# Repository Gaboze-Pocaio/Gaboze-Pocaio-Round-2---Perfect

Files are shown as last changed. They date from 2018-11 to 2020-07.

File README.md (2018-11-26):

-----

# Where Can I Buy One
> You can purchase an assembled Gaboze Pocaio - Round 2 on [Tindie](https://www.tindie.com/products/thirtytwoteeth/gaboze-pocaio-round-2/)

[](https://www.tindie.com/products/thirtytwoteeth/gaboze-pocaio-round-2/)

-----

# Gaboze Pocaio
> This is it!

Based on the popularity of the original [Gaboze Pocaio](https://github.com/32teeth/GabozePocaio-Round1) and it's many updates. We have taken the *Gaboze Pocaio - Plus Edition* which featured the 2.6" TFT *(ILI9342)* and added a few more features

Project Code Name: ***'Play It Again'***

## Introduction
> Do we need one?

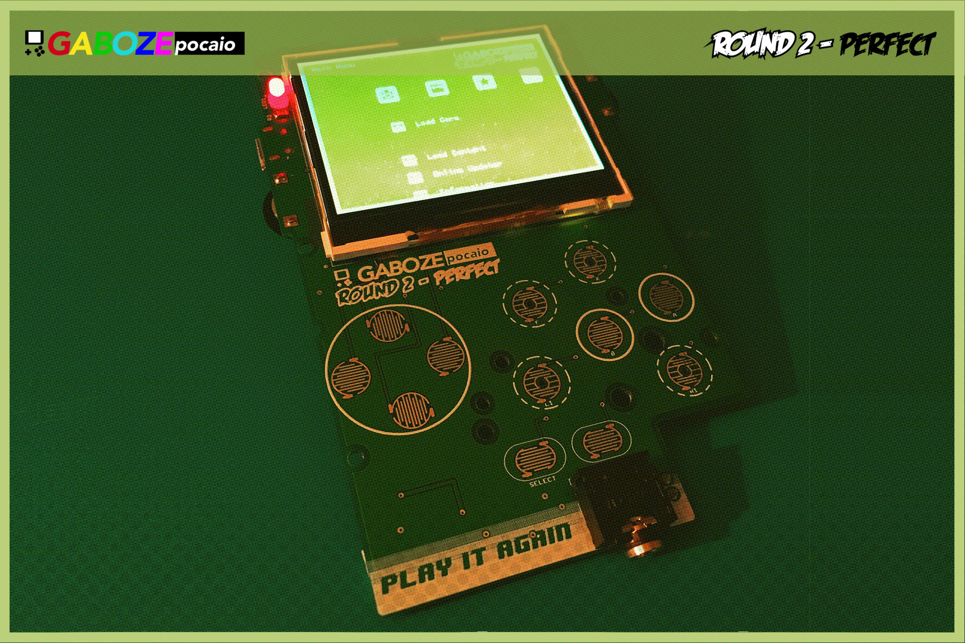
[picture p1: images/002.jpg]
Play It Again


### Features
> Things you can find on this kit

- 2.6" TFT LCD
- USB peripheral support for *3.3v accessories* (ie: keyboards)
- Brightness Control Thumbwheel
- Volume Control Thumbwheel
- Power LED - 3mm diffused
- New Conductive Pads
- Through Hole Raspberry Pi Zero Mounting Header
- Battery Charger (TP4056 Module)
- Headphone Jack (LM4857)
- Speaker capability (LM4857)
- Audio Amp (LM4857)

| Top Side Features | Bottom Side Features |
| - | - |
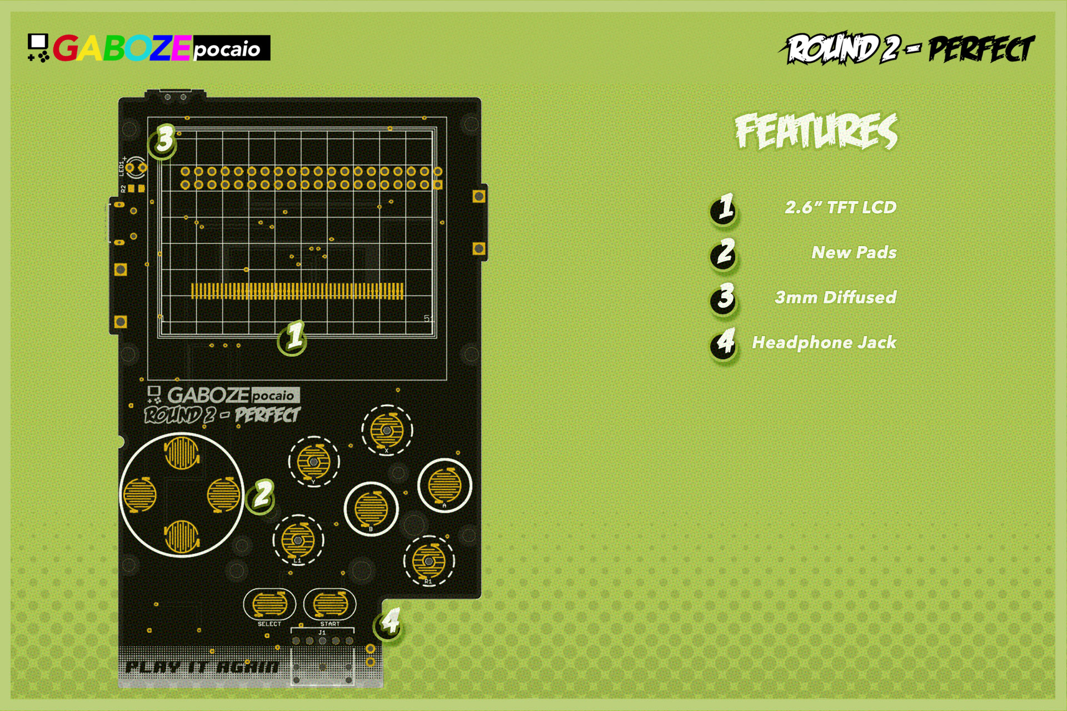
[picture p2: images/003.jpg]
Top
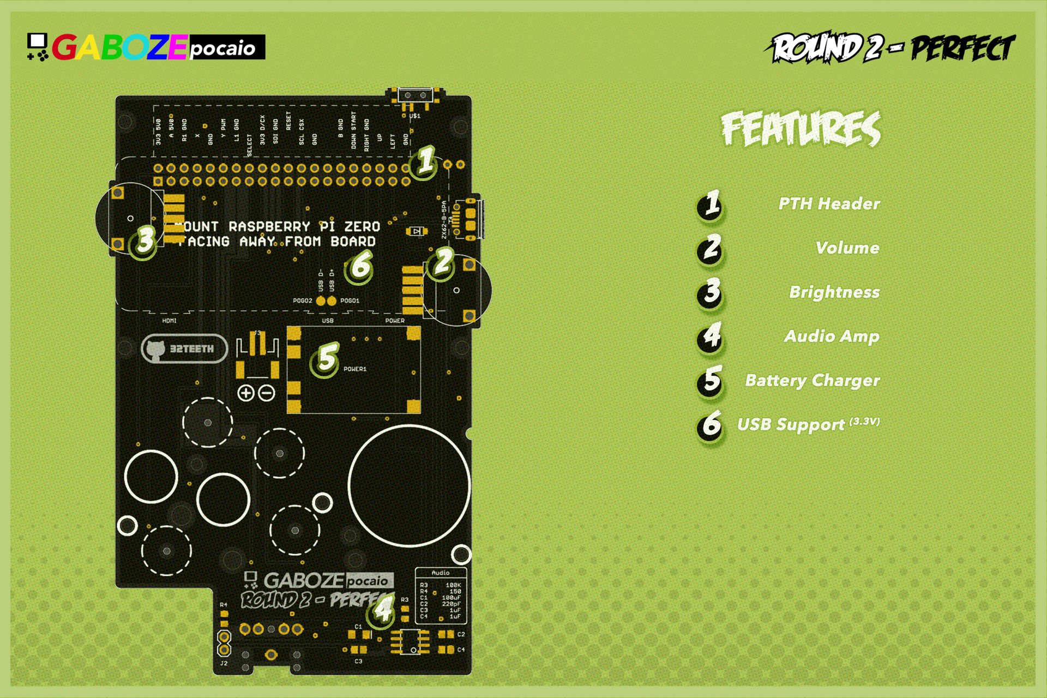
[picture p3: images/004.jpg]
Bottom
|  |  |

### Platform Support:

- [x] [Emulation Station](http://www.emulationstation.org/)
- [x] [Lakka](http://www.lakka.tv/)
- [x] [RetroPie](https://retropie.org.uk/)

*For [Lakka](http://www.lakka.tv/) implementation you can follow the ['paint by numbers' tutorial](https://github.com/32teeth/Lakka-For-Gaboze-Pocaio)*

#### New Feature Discussion
> A little more behind the features

##### TFT
> A new screen

An adoption from the *Gaboze Pocaio - Plus Edition*. The screen is now a 2.6" TFT, which fills the screen area of the Game Boy Pocket shell much better. No more resizing of the video driver output!

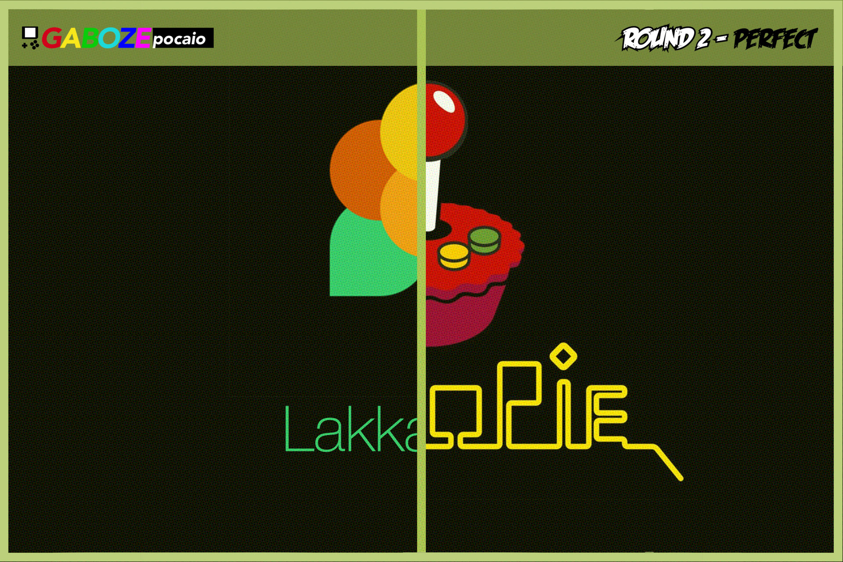
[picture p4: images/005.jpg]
Lakka or RetroPie


##### Brightness Control
> Mechanical Adjustment FTW

Although there are many implementations of *software* based screen brightness adjustment. This model features a **thubwheel**, which means you don't need to worry about knowing how, or where to put the *software* based controls.

This also allows for using different *Operating Systems* and having brightness control out of the box

##### Through Hole Header
> No more loose connections

With the new Raspberry Pi Zero mounting system using a through hole header, you will no longer loosen the pin connection if using an unregulated (non temperature) control soldering iron...   ...yay

The short insulation on the header also means you can mount the Raspberry Pi flat against the headers

##### New Conductive Pads
> Better response. Simply put

With a redesigned conductive pad, you can now have a better response rate to your silicon aftermarket pads.

##### USB peripheral support
> No connection? No Problem

This is a 3.3V USB peripheral support, like keyboards (not the LED mechanical ones), older joysticks / gamepads *(can you say retro pads!)*

One of the most requested features is to be able to use your keyboard and terminal without having to connect to the network, SSH, SCP, or FTP.

##### Power LED
> Domed and diffused

We replaced the surface mount power indicator LED with a through hole domed and diffused 3mm LED. This fits perfectly in the LED hole of the original and aftermarket *Game Boy Pocket* shell

## What you need
> Batteries not included

In order to complete your build. You will need:

- Raspberry Pi Zero W
- LiPo Battery
- Micro SD Card
- Gameboy Pocket Shell

## Releases
> Retro Pie or Lakka - You Decide

* [Retro Pie](https://github.com/32teeth/GabozePocaio-Round2/releases/tag/RetroPie)
* [Lakka](https://github.com/32teeth/GabozePocaio-Round2/releases/tag/Lakka)

### Direct Downloads

#### Retro Pie
* [IMG](http://gameboy.32teeth.org/Gaboze-Round2-RetroPie.img)
* [GZIP](http://gameboy.32teeth.org/Gaboze-Round2-RetroPie.gz)

#### Lakka
* [IMG](http://gameboy.32teeth.org/Gaboze-Round2-Lakka.img)
* [GZIP](http://gameboy.32teeth.org/Gaboze-Round2-Lakka.gz)

### Get In Touch

|    [](https://github.com/32teeth)[](https://www.instagram.com/gabozepocaio/)[](https://www.facebook.com/messages/t/gabozepocaio)[](https://www.paypal.me/32teeth/5USD)  |
| ---- |
| Find us on the internet and lets chat |

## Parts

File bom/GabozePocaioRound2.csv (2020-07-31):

Designator | Description | Manufacturer Part Number | Purchase Link | Quantity
D1 | DIODE SCHOTTKY 20V 1A SOD123FL | SM5817PL-TP | https://www.digikey.ca/product-detail/en/micro-commercial-co/SM5817PL-TP/SM5817PL-TPMSCT-ND/1793410 | 1
R2 | RES SMD 1.5K OHM 0.1% 1/4W 0805 | ERJ-PB6B1501V | https://www.digikey.ca/product-detail/en/panasonic-electronic-components/ERJ-PB6B1501V/P20612CT-ND/6214867 | 1
R3 | RES 100K OHM 5% 1/4W 0805 | RPC0805JT100KCT | https://www.digikey.ca/product-detail/en/stackpole-electronics-inc/RPC0805JT100K/RPC0805JT100KCT-ND/5766007 | 1
R4 | RES 150 OHM 1% 1/4W 0805 | RNCP0805FTD150R | https://www.digikey.ca/product-detail/en/stackpole-electronics-inc/RNCP0805FTD150R/RNCP0805FTD150RCT-ND/2240550 | 1
R5, R10 | Replacement Volume Switch for Game boy | N/A | https://www.aliexpress.com/item/Replacement-Volume-Switch-for-Game-boy-for-GBA-GBC-Motherboard-Potentiomete-100pcs-lot/32830491244.html | 2
C1 | CAP TANT 100UF 4V 20% 1206 | F930G107MAA | https://www.digikey.ca/product-detail/en/avx-corporation/F930G107MAA/478-8134-1-ND/4005954 | 1
C3,C4 | CAP CER 1UF 25V X7R 0805 | C0805C105K3RACTU | https://www.digikey.ca/product-detail/en/kemet/C0805C105K3RACTU/399-8004-1-ND/3471727 | 2
C2 | CAP CER 0.22UF 50V X7R 0805 | C0805C224K5RACTU | https://www.digikey.ca/product-detail/en/kemet/C0805C224K5RACTU/399-3491-1-ND/754784 | 1
J1 | CONN JACK STEREO 3.5MM R/A | CP1-3525NG-PI-ND | https://www.digikey.ca/product-detail/en/cui-inc/SJ1-3525NG-PI/CP1-3525NG-PI-ND/2295991 | 1
J2 | SPEAKER 8OHM 250MW TOP PORT 80DB | PSR-20F08S-JQ | https://www.digikey.ca/product-detail/en/mallory-sonalert-products-inc/PSR-20F08S-JQ/458-1122-ND/2071438 | 1
J3 | CONN HEADER PH SIDE 2POS 2MM SMD | S2B-PH-SM4-TB(LF)(SN | https://www.digikey.ca/product-detail/en/jst-sales-america-inc/S2B-PH-SM4-TB(LF)(SN)/455-1749-1-ND/926846 | 1
J4 | CONN RCPT USB MICRO B SMD | ZX62D-B-5P8(30) | https://www.digikey.ca/product-detail/en/hirose-electric-co-ltd/ZX62D-B-5P8-30/H125272CT-ND/5994758 | 1
U1 | IC AMP AUDIO PWR 1W MONO 8SOIC | LM4875MX-NOPB | https://www.digikey.ca/product-detail/en/texas-instruments/LM4875MX-NOPB/296-35282-1-ND/3738990 | 1
LED1 | LED RED DIFFUSED 3MM ROUND T/H | 151031SS04000 | https://www.digikey.ca/product-detail/en/wurth-electronics-inc/151031SS04000/732-5005-ND/4489979 | 1
U$1 | SWITCH SLIDE SPDT 300MA 4V | MA12RTR | https://www.digikey.ca/product-detail/en/apem-inc/MA12RTR/679-1847-1-ND/1973774 | 1
U$2 | 2.6 inch TFT liquid horizontal screen ILI9342 3/4 line SPI MCU8 bit 16 touch | N/A | https://www.aliexpress.com/item/-/32861496981.html | 1
PI1 | CONN HEADER .100" 40POS SNGL TIN | TLW-120-06-T-D | https://www.digikey.ca/product-detail/en/samtec-inc/TLW-120-06-T-D/SAM1097-20-ND/1104960 | 1
POWER1 | Lithium Battery Charging Board | N/A | https://www.aliexpress.com/item/Free-Shipping-1PCS-5V-Micro-USB-1A-18650-Lithium-Battery-Charging-Board-With-Protection-Charger-Module/32476957358.html | 1
POGO1, POGO2 | ULTRA LOW PROFILE SPRING PIN | 0965-0-15-20-80-14-11-0 | https://www.digikey.ca/product-detail/en/0965-0-15-20-80-14-11-0/ED1649-ND/2784013 | 2

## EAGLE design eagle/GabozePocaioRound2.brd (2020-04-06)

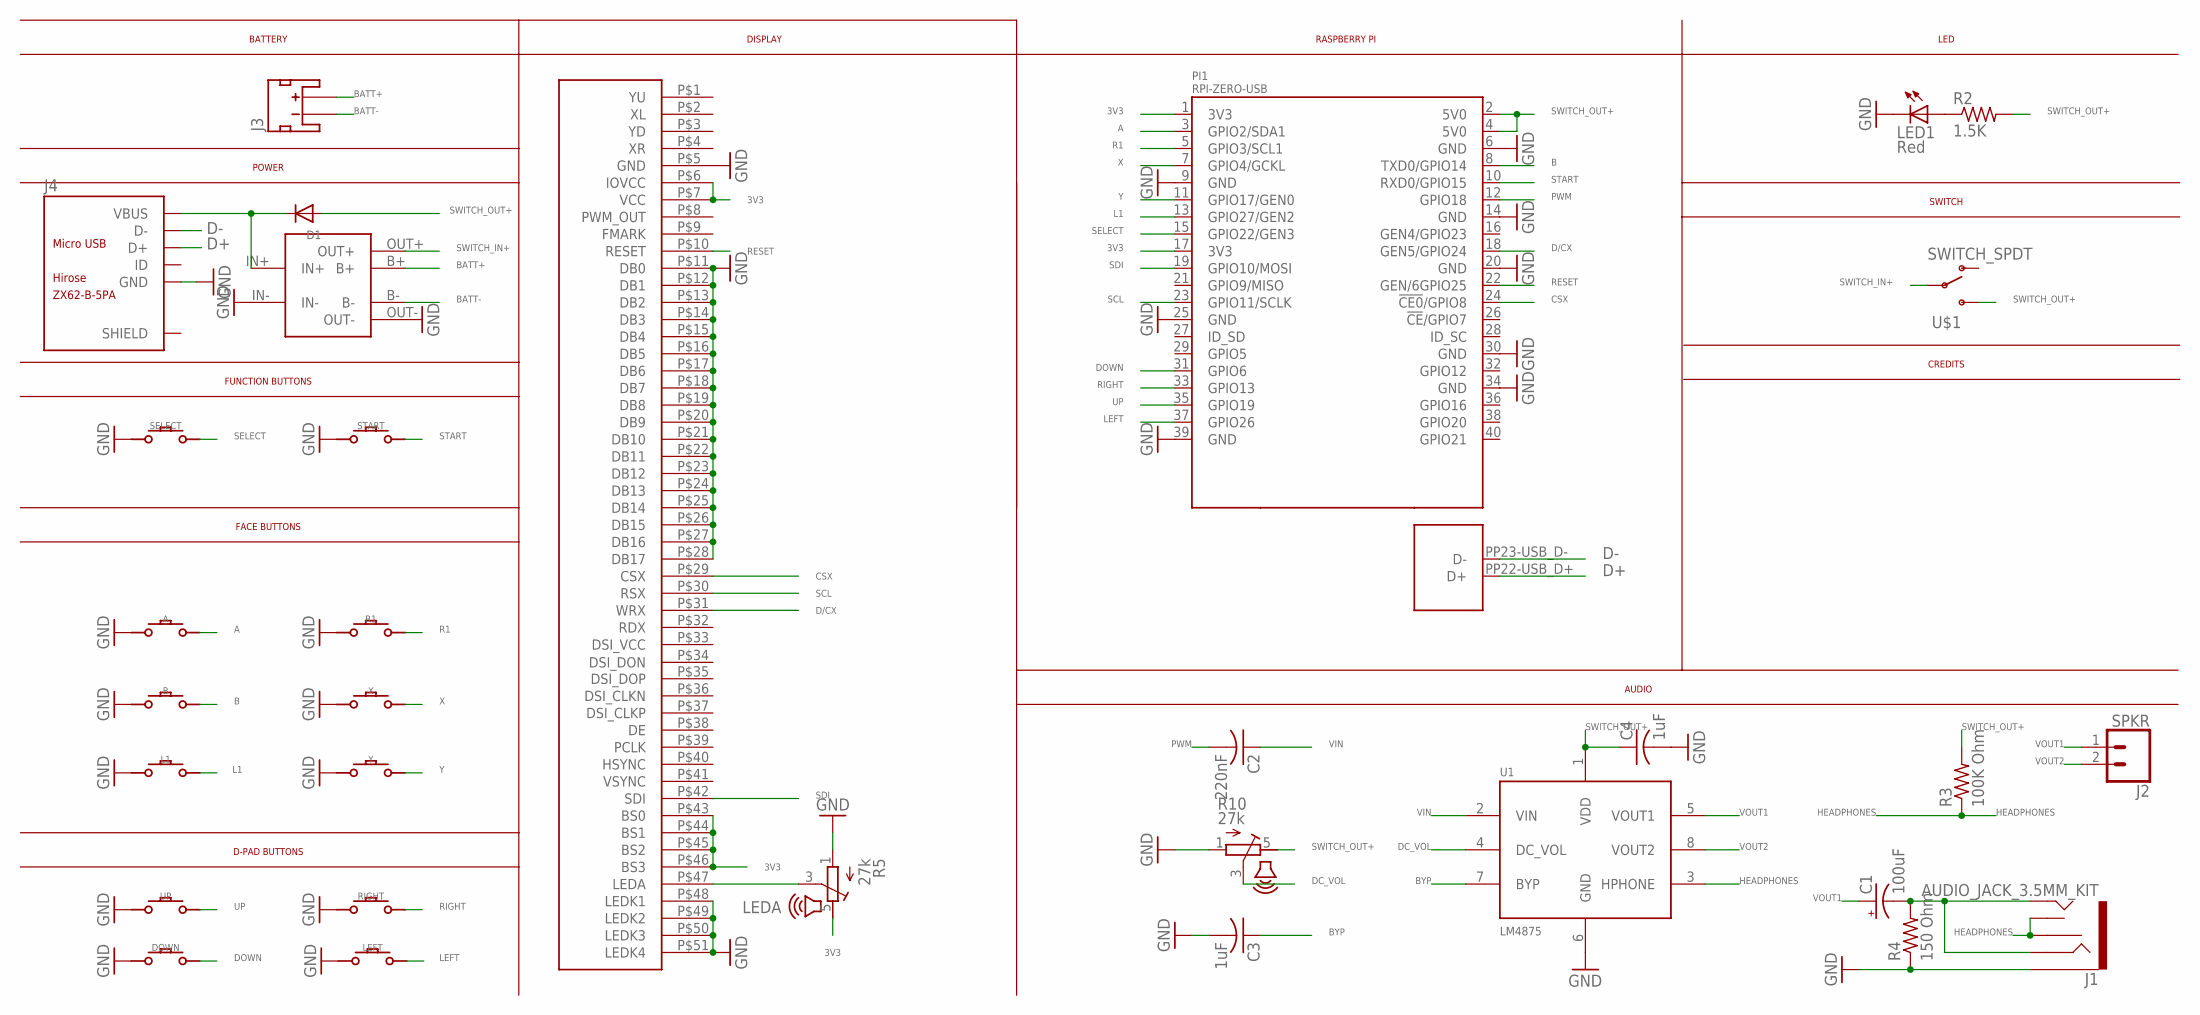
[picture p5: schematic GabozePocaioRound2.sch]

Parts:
A: CONDUCTIVE_BUTTONCONDUCTIVE_BUTTON_THICK; CONDUCTIVE_BUTTON_THICK
B: CONDUCTIVE_BUTTONCONDUCTIVE_BUTTON_THICK; CONDUCTIVE_BUTTON_THICK
C1: 100uF; EIA3216
C2: 220nF; C0805
C3, C4: 1uF; C0805
D1: DIODE_SOD-123FL; SOD-123FL
DOWN: CONDUCTIVE_BUTTONCONDUCTIVE_BUTTON_DIRECTIONAL_TH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; CONDUCTIVE_BUTTON_DIRECTIONAL_THICK
J1: AUDIO_JACK_3.5MM_KIT; AUDIO-JACK-KIT
J2: SPKR; 1X02
J3: Batt Conn; JST-2-SMD
J4: ZX62-B-5PA; MICRO-USB5+6P-SMD-0.65-AB
L1: CONDUCTIVE_BUTTON_DRILLCONDUCTIVE_BUTTON_DRILL_TH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; CONDUCTIVE_BUTTON_THICK_DRILL
LED1: Red; LED3MM
LEFT: CONDUCTIVE_BUTTONCONDUCTIVE_BUTTON_DIRECTIONAL_TH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; CONDUCTIVE_BUTTON_DIRECTIONAL_THICK
PI1: RPI-ZERO-USB; RPI-ZERO-TH-USB-POGO
POWER1: TP4056
R1: CONDUCTIVE_BUTTON_DRILLCONDUCTIVE_BUTTON_DRILL_TH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; CONDUCTIVE_BUTTON_THICK_DRILL
R2: 1.5K; R0805
R3: 100K Ohm; R0805
R4: 150 Ohm; R0805
R5, R10: 27k; VOLUME
RIGHT: CONDUCTIVE_BUTTONCONDUCTIVE_BUTTON_DIRECTIONAL_TH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; CONDUCTIVE_BUTTON_DIRECTIONAL_THICK
SELECT: CONDUCTIVE_BUTTON_STARTSELECTCONDUCTIVE_BUTTON_TH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; CONDUCTIVE_BUTTON_THICK_STARTSELECT
START: CONDUCTIVE_BUTTON_STARTSELECTCONDUCTIVE_BUTTON_TH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; CONDUCTIVE_BUTTON_THICK_STARTSELECT
U1: LM4875; SOIC8
U$1: SWITCH_SPDT; KPS-1290
U$2: TFT-DISPLAY-2.6-51PIN
UP: CONDUCTIVE_BUTTONCONDUCTIVE_BUTTON_DIRECTIONAL_TH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; CONDUCTIVE_BUTTON_DIRECTIONAL_THICK
X: CONDUCTIVE_BUTTON_DRILLCONDUCTIVE_BUTTON_DRILL_TH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; CONDUCTIVE_BUTTON_THICK_DRILL
Y: CONDUCTIVE_BUTTON_DRILLCONDUCTIVE_BUTTON_DRILL_TH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; CONDUCTIVE_BUTTON_THICK_DRILL

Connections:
3V3: PI1.1 (3V3), PI1.17 (3V3), R5.5 (E), U$2.P$6 (IOVCC), U$2.P$7 (VCC), U$2.P$43 (BS0), U$2.P$44 (BS1), U$2.P$45 (BS2), U$2.P$46 (BS3)
A: A.P$ACTIVE, PI1.3 (GPIO2/SDA1)
B: B.P$ACTIVE, PI1.8 (TXD0/GPIO14)
BATT+: J3.2 (+), POWER1.B+
BATT-: J3.1 (-), POWER1.B-
BYP: C3.1, U1.7 (BYP)
CSX: PI1.24 (!CE0!/GPIO8), U$2.P$29 (CSX)
D+: J4.3 (D+), PI1.PP22-USB_D+ (D+)
D-: J4.2 (D-), PI1.PP23-USB_D- (D-)
D/CX: PI1.18 (GEN5/GPIO24), U$2.P$31 (WRX)
DC_VOL: R10.3 (S), U1.4 (DC_VOL)
DOWN: DOWN.P$ACTIVE, PI1.31 (GPIO6)
GND: A.P$GND, B.P$GND, C3.2, C4.2, DOWN.P$GND, J1.SLEEVE, J4.5 (GND), L1.P$GND, LED1.K (C), LEFT.P$GND, PI1.6 (GND), PI1.9 (GND), PI1.14 (GND), PI1.20 (GND), PI1.25 (GND), PI1.30 (GND), PI1.34 (GND), PI1.39 (GND), POWER1.IN-, POWER1.OUT-, R1.P$GND, R4.1, R5.1 (A), R10.1 (A), RIGHT.P$GND, SELECT.P$GND, SELECT.P$GND1 (P$GND), SELECT.P$GND2 (P$GND), SELECT.P$GND3 (P$GND), START.P$GND, START.P$GND1 (P$GND), START.P$GND2 (P$GND), START.P$GND3 (P$GND), U1.6 (GND), U$2.P$5 (GND), U$2.P$11 (DB0), U$2.P$12 (DB1), U$2.P$13 (DB2), U$2.P$14 (DB3), U$2.P$15 (DB4), U$2.P$16 (DB5), U$2.P$17 (DB6), U$2.P$18 (DB7), U$2.P$19 (DB8), U$2.P$20 (DB9), U$2.P$21 (DB10), U$2.P$22 (DB11), U$2.P$23 (DB12), U$2.P$24 (DB13), U$2.P$25 (DB14), U$2.P$26 (DB15), U$2.P$27 (DB16), U$2.P$28 (DB17), U$2.P$48 (LEDK1), U$2.P$49 (LEDK2), U$2.P$50 (LEDK3), U$2.P$51 (LEDK4), UP.P$GND, X.P$GND, Y.P$GND
HEADPHONES: J1.RSH, J1.TSH, R3.1, U1.3 (HPHONE)
L1: L1.P$ACTIVE, PI1.13 (GPIO27/GEN2)
LED: LED1.A, R2.1
LEDA: R5.3 (S), U$2.P$47 (LEDA)
LEFT: LEFT.P$ACTIVE, PI1.37 (GPIO26)
PWM: C2.2, PI1.12 (GPIO18)
R1: PI1.5 (GPIO3/SCL1), R1.P$ACTIVE
RESET: PI1.22 (GEN/6GPIO25), U$2.P$10 (RESET)
RIGHT: PI1.33 (GPIO13), RIGHT.P$ACTIVE
SCL: PI1.23 (GPIO11/SCLK), U$2.P$30 (RSX)
SDI: PI1.19 (GPIO10/MOSI), U$2.P$42 (SDI)
SELECT: PI1.15 (GPIO22/GEN3), SELECT.P$ACTIVE, SELECT.P$ACTIVE1 (P$ACTIVE), SELECT.P$ACTIVE2 (P$ACTIVE), SELECT.P$ACTIVE3 (P$ACTIVE)
START: PI1.10 (RXD0/GPIO15), START.P$ACTIVE, START.P$ACTIVE1 (P$ACTIVE), START.P$ACTIVE2 (P$ACTIVE), START.P$ACTIVE3 (P$ACTIVE)
SWITCH_IN+: POWER1.OUT+, U$1.P
SWITCH_OUT+: C4.1, D1.A, PI1.2 (5V0), PI1.4 (5V0), R2.2, R3.2, R10.5 (E), U1.1 (VDD), U$1.S
UP: PI1.35 (GPIO19), UP.P$ACTIVE
VIN: C2.1, U1.2 (VIN)
VIN1: C1.-, J1.RING, J1.TIP, R4.2
VOUT1: C1.+, J2.1, U1.5 (VOUT1)
VOUT2: J2.2, U1.8 (VOUT2)
VUSB: D1.C, J4.1 (VBUS), POWER1.IN+
X: PI1.7 (GPIO4/GCKL), X.P$ACTIVE
Y: PI1.11 (GPIO17/GEN0), Y.P$ACTIVE

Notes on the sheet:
D-PAD BUTTONS
FACE BUTTONS
FUNCTION BUTTONS
POWER
BATTERY
SWITCH
LED
DISPLAY
RASPBERRY PI
AUDIO
CREDITS

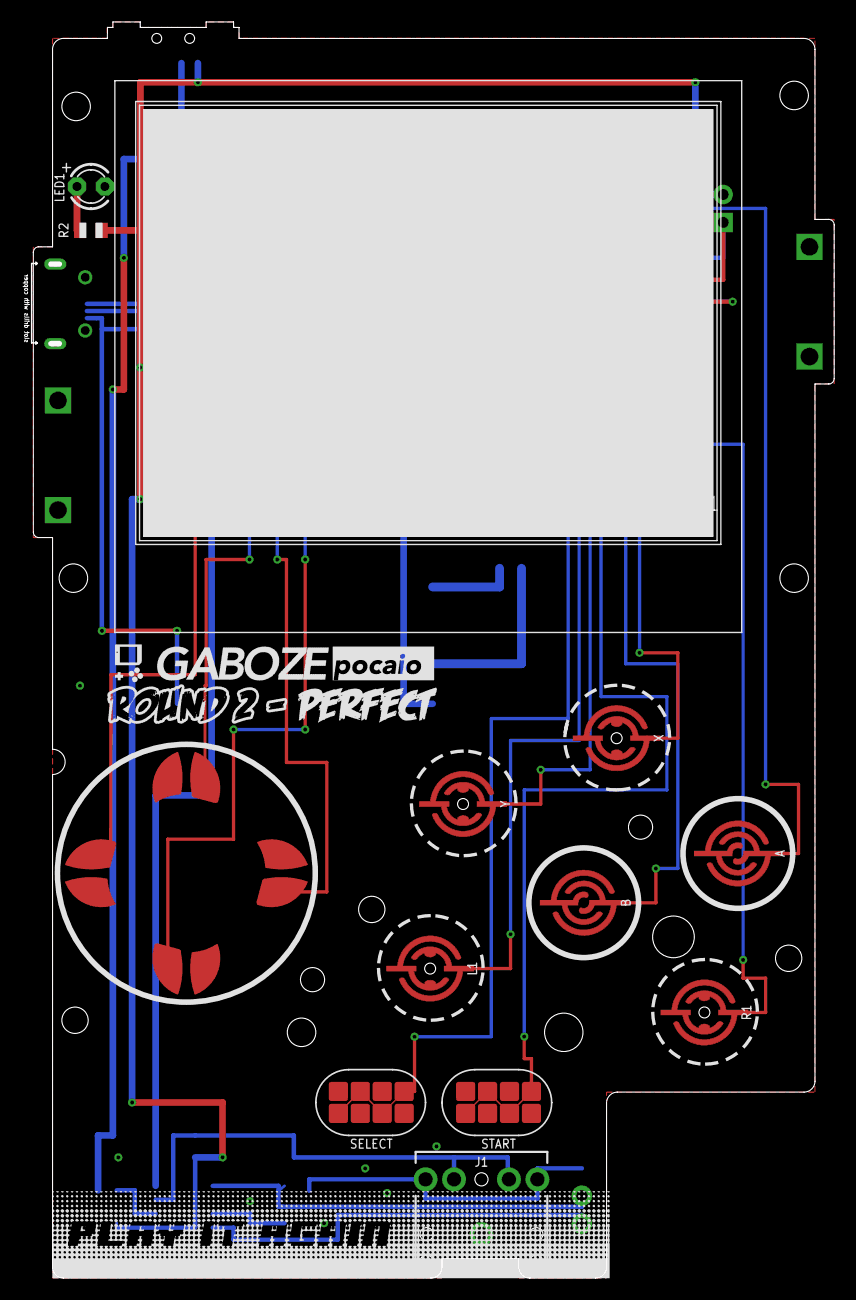
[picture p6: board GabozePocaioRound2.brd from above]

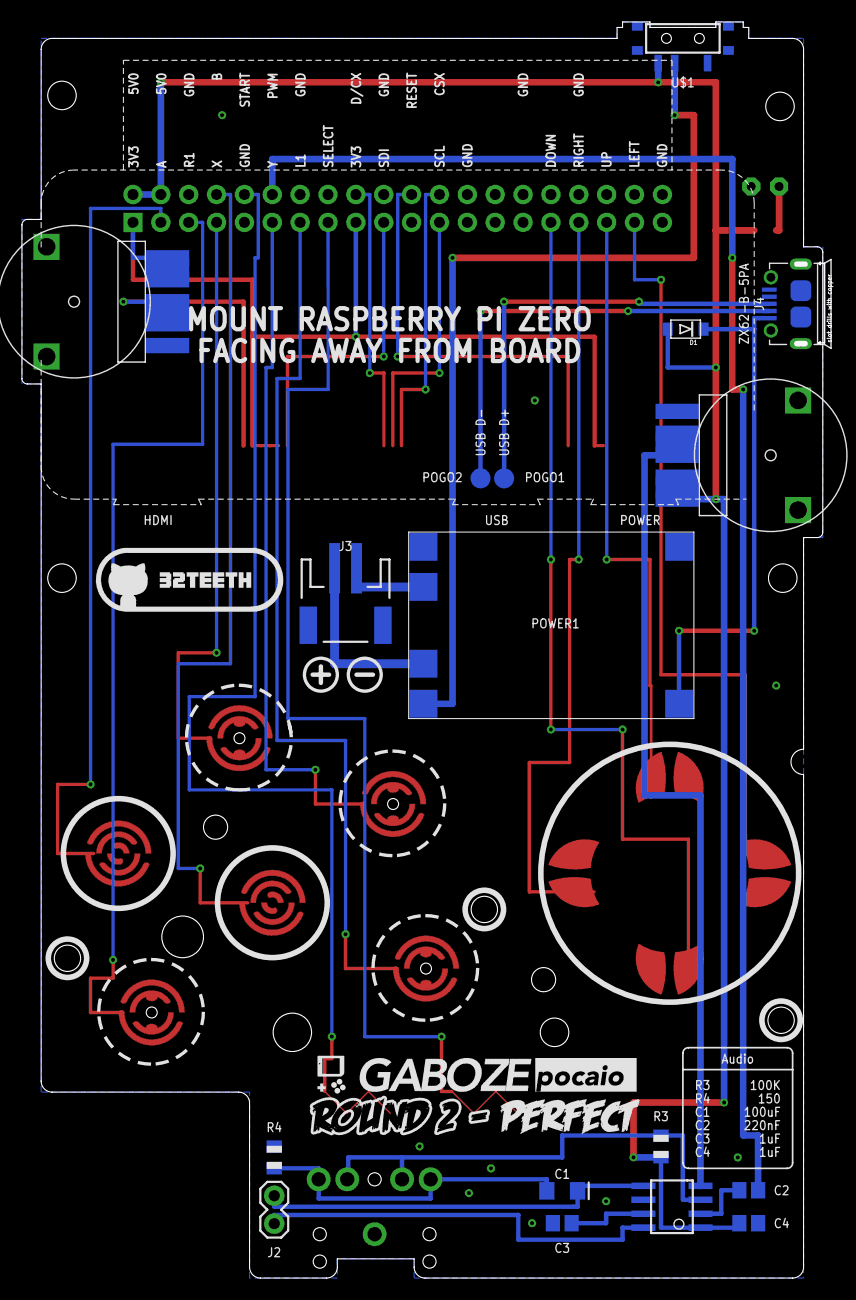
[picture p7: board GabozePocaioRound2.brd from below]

Board: 2 copper layers, 73.0 x 114.5 mm, 32 parts (16 on the bottom side), 36 nets.

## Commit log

2018-11-06 Tue 6 Nov 2018 09:43:30 EST
    [GabozePocaioRound2.csv]
2018-11-16 Fri 16 Nov 2018 18:18:55 EST - Assembly Tutuorial
2019-01-17 Thu 17 Jan 2019 10:50:48 EST - Happy Chinese New Year w/ Eagle and Gerber Release
    [GabozePocaioRound2.GBL, GabozePocaioRound2.GBO, GabozePocaioRound2.GBP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]
2019-05-01 Wed 1 May 2019 12:41:43 EDT - changed thermals
    [GabozePocaioRound2.GBL, GabozePocaioRound2.GBO, GabozePocaioRound2.GBP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]
2020-04-06 Correct the value of C2 to 220nF in Eagle and BOM files
    In the datasheet of LM4875 [1], Texas Instruments recommends
    a 0.22uF (which is 220nF [2]) AC-coupling capacitor at the
    audio input port [3]. However, in the Eagle and BOM files of
    Gaboze Pocaio Round 2, the capacitor value was specified
    as 220pF by accident. Experiments showed that using a 220pF
    capacitor instead of 220nF causes an audible distortion
    of the headphone output, which is characterized by the lack
    of bass due to the RC high-pass filter action.
    This commit corrects the component value C2 from 220pF to
    220nF in Eagle schematic and board design files. Also, in
    the BOM,
    C2,CAP CER 220PF 50V X7R 0805,C0805C221M5RACTU
    has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
    [GabozePocaioRound2.brd, GabozePocaioRound2.csv, GabozePocaioRound2.sch]

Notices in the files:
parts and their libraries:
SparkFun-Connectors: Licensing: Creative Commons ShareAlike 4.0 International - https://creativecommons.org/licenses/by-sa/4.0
